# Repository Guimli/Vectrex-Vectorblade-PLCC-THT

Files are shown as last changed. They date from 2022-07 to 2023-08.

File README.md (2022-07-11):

# Vectrex-Vectorblade-PLCC-THT

PCB for VectorBlade with PLCC format memory on through-hole support.

I preferred to use a through-hole mount because it is more solid. And it has a hole on the bottom to eject the PLCC board easily without a puller.
The bracket is 8.1mm, which is only slightly more than the space between the PCB and the top of the plastic shell of the cartridge. I therefore recommend reducing the size of the bracket by removing the feet from the PLCC bracket.

This board is currently being tested and is not ready for production.

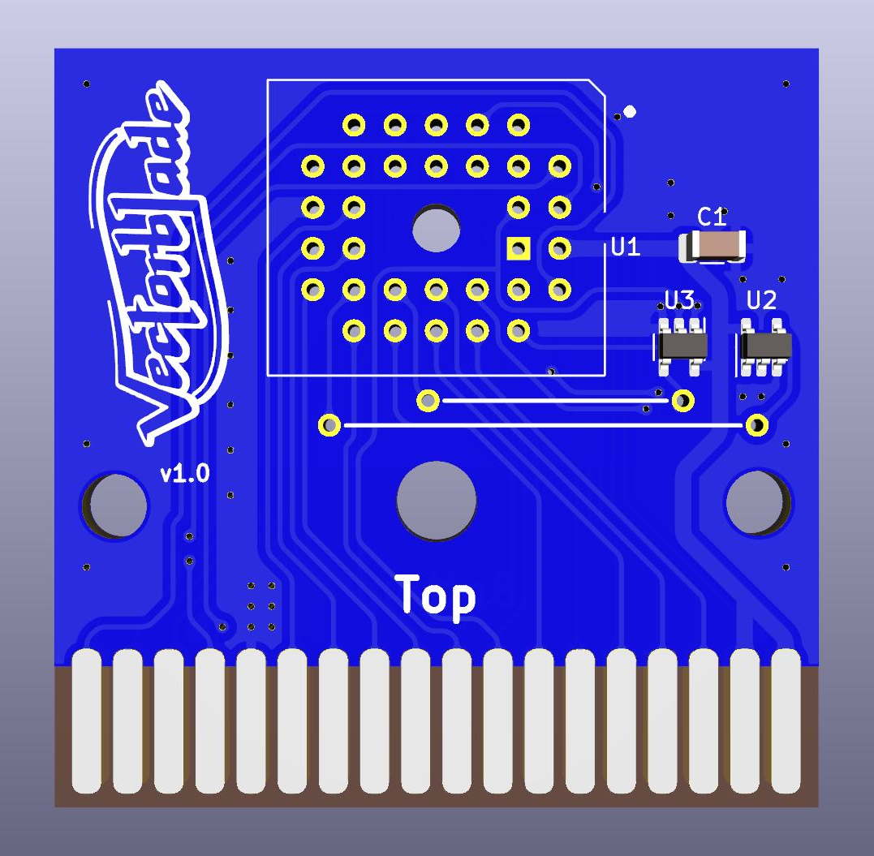
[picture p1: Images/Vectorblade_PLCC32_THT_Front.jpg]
PCB Top


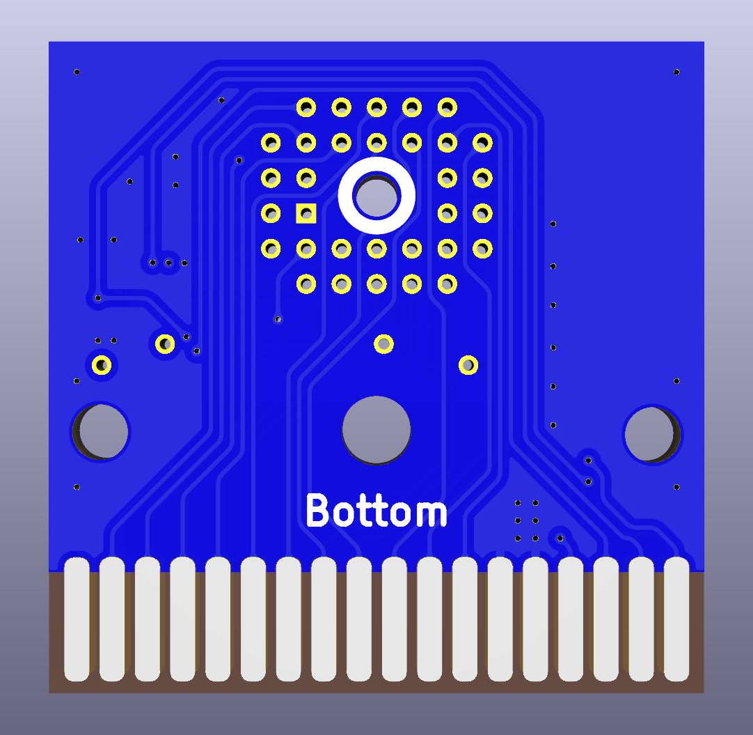
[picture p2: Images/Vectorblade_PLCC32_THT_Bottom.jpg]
PCB Bottom


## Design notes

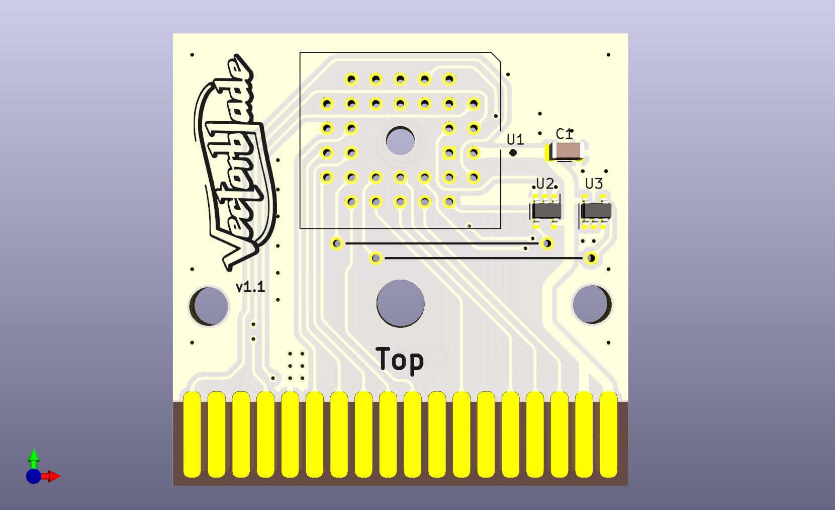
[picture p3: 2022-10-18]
Images/Vectorblade_PLCC32_THT.jpg

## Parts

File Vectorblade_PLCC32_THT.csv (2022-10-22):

Id | Référence | Empreinte | Quantité | Désignation | Fournisseur et réf
1 | U1 | PLCC-32_THT-Socket | 1 | SST39SF020
2 | U3 | SOT-23-5 | 1 | 74AHC1G04
3 | C1 | C_1206_3216Metric | 1 | 100n
4 | U2 | SOT-23-5 | 1 | 74AHC1G08

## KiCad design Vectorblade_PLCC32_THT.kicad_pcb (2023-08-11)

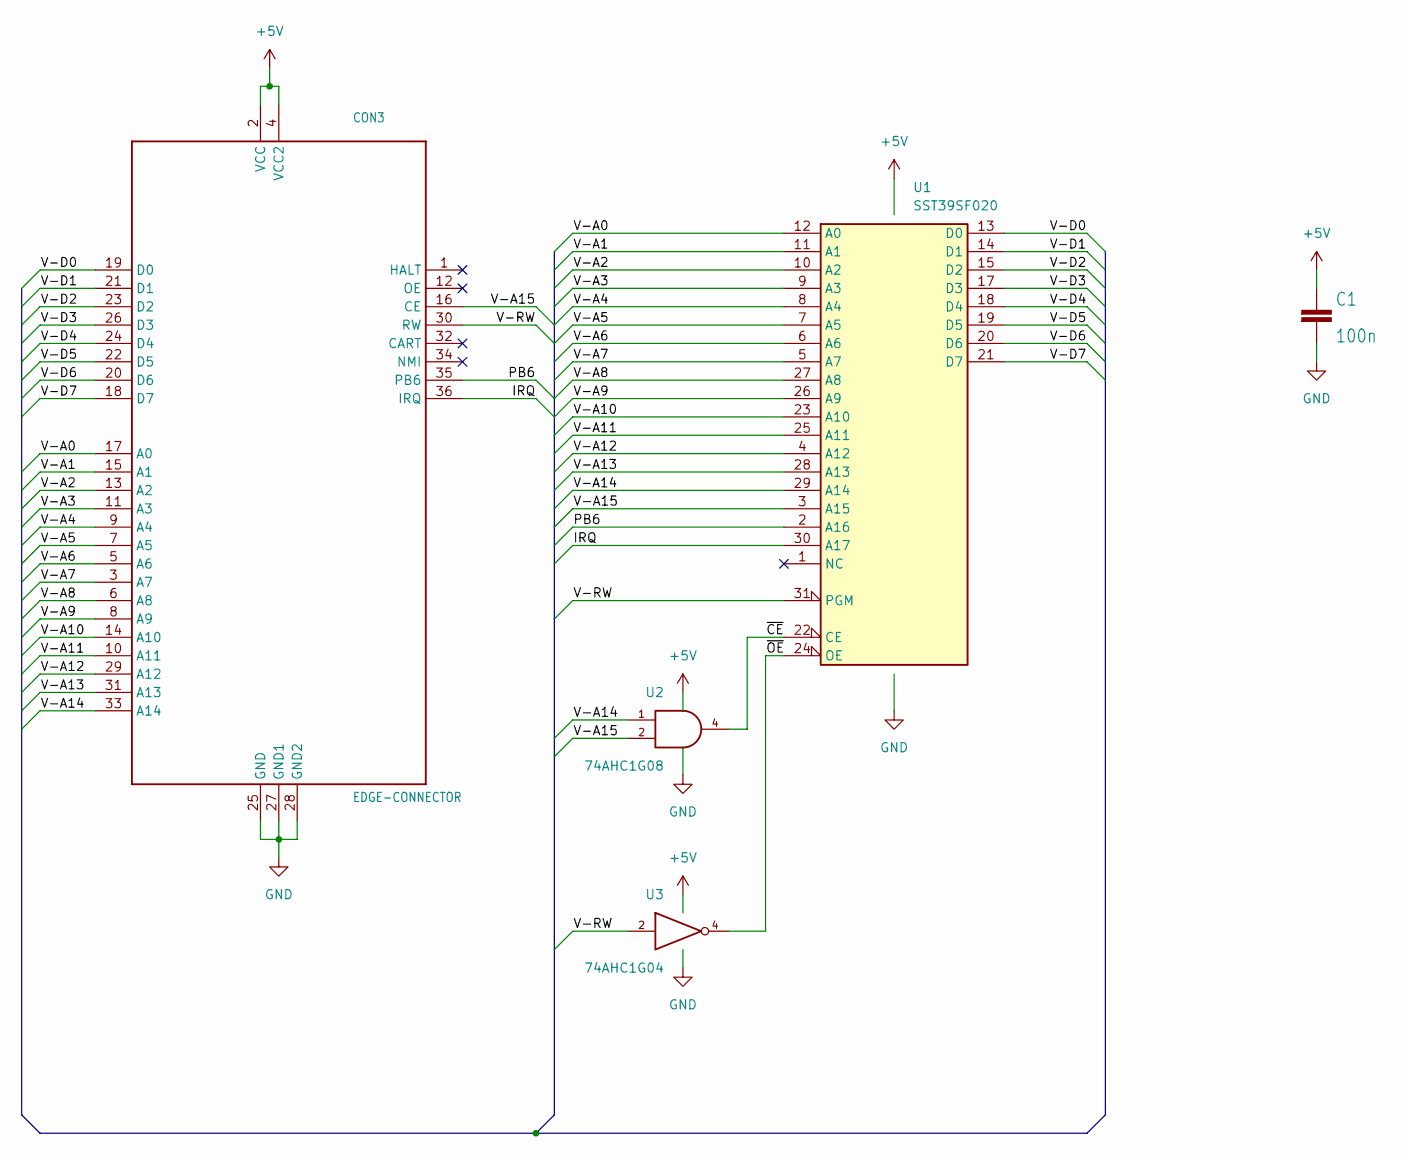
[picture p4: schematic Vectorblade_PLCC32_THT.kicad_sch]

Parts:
C1: 100n; C_0805_2012Metric
CON3: EDGE-CONNECTOR
U1: SST39SF020; PLCC-32_THT-Socket
U2: 74AHC1G08; SOT-23-5
U3: 74AHC1G04; SOT-23-5

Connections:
+5V: C1.1, CON3.2 (VCC), CON3.4 (VCC2), U1.32 (VCC), U2.5 (VCC), U3.5 (VCC)
/IRQ: CON3.36 (IRQ), U1.30 (A17)
/PB6: CON3.35 (PB6), U1.2 (A16)
/V-A0: CON3.17 (A0), U1.12 (A0)
/V-A1: CON3.15 (A1), U1.11 (A1)
/V-A2: CON3.13 (A2), U1.10 (A2)
/V-A3: CON3.11 (A3), U1.9 (A3)
/V-A4: CON3.9 (A4), U1.8 (A4)
/V-A5: CON3.7 (A5), U1.7 (A5)
/V-A6: CON3.5 (A6), U1.6 (A6)
/V-A7: CON3.3 (A7), U1.5 (A7)
/V-A8: CON3.6 (A8), U1.27 (A8)
/V-A9: CON3.8 (A9), U1.26 (A9)
/V-A10: CON3.14 (A10), U1.23 (A10)
/V-A11: CON3.10 (A11), U1.25 (A11)
/V-A12: CON3.29 (A12), U1.4 (A12)
/V-A13: CON3.31 (A13), U1.28 (A13)
/V-A14: CON3.33 (A14), U1.29 (A14), U2.1
/V-A15: CON3.16 (CE), U1.3 (A15), U2.2
/V-D0: CON3.19 (D0), U1.13 (D0)
/V-D1: CON3.21 (D1), U1.14 (D1)
/V-D2: CON3.23 (D2), U1.15 (D2)
/V-D3: CON3.26 (D3), U1.17 (D3)
/V-D4: CON3.24 (D4), U1.18 (D4)
/V-D5: CON3.22 (D5), U1.19 (D5)
/V-D6: CON3.20 (D6), U1.20 (D6)
/V-D7: CON3.18 (D7), U1.21 (D7)
/V-RW: CON3.30 (RW), U1.31 (PGM), U3.2
/~CE: U1.22 (CE), U2.4
/~OE: U1.24 (OE), U3.4
GND: C1.2, CON3.25 (GND), CON3.27 (GND1), CON3.28 (GND2), U1.16 (GND), U2.3 (GND), U3.3 (GND)

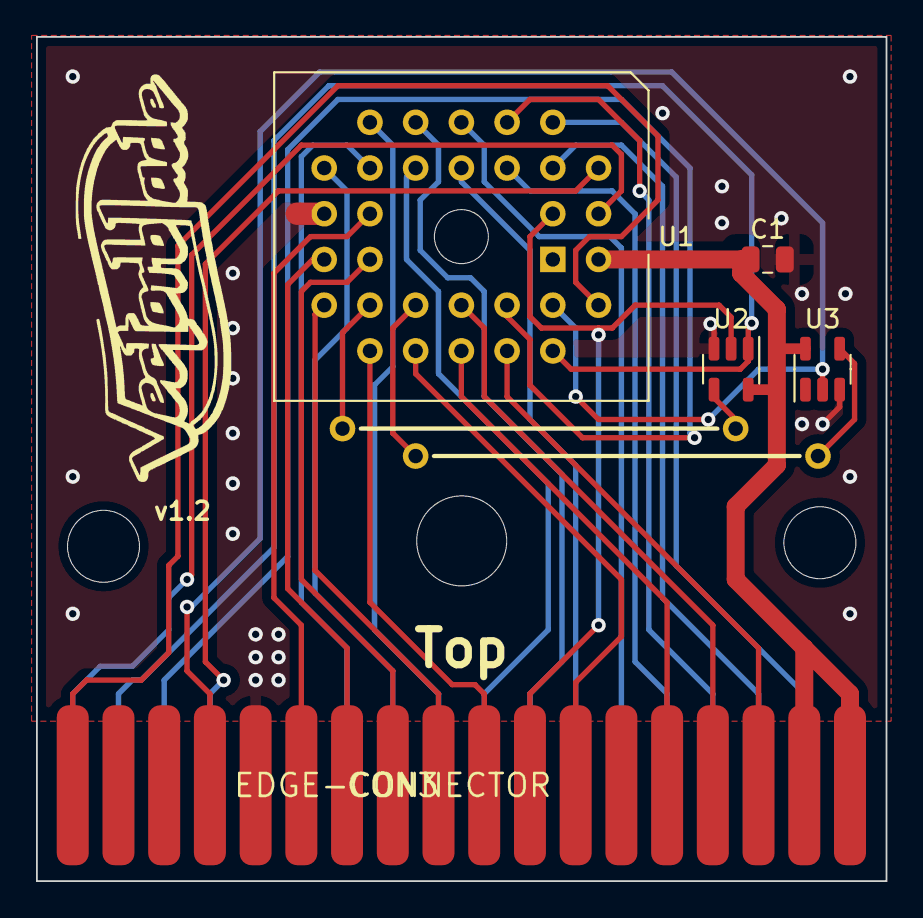
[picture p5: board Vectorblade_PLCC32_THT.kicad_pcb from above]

Board: 2 copper layers, 47.2 x 46.9 mm, 8 parts (0 on the bottom side), 31 nets.

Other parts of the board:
@HOLE0, @HOLE1, @HOLE2: (no value)

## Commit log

2022-10-18 Correct CE error
    Correct CE schematic and board error
    [MC-32PLCC-THT.stl, MC-32PLCC.FCStd, Vectorblade.kicad_sch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]
2022-10-22 Correct a roud track
    [Vectorblade_PLCC32_THT.csv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]
2022-11-27 I forgot to connect A15
    Shame !
    [Vectorblade_PLCC32_THT.kicad_pcb, Vectorblade_PLCC32_THT.kicad_sch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]
2022-11-28 Remove Edge-Connector Silkscreen
    [Vectorblade_PLCC32_THT_Kicad7-B_Cu.gbr, Vectorblade_PLCC32_THT_Kicad7-B_Mask.gbr, Vectorblade_PLCC32_THT_Kicad7-B_Paste.gbr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]
2023-08-11 Update Gerber
    [Vectorblade_PLCC32_THT.kicad_pcb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]
